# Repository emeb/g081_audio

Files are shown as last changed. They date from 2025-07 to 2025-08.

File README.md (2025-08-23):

# g081_audio

A Eurorack reverb module based on the STM32G081

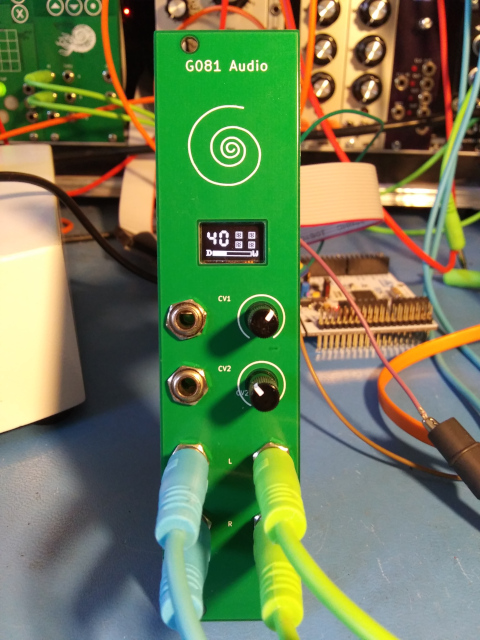
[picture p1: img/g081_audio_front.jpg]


## What it is

The G081 Audio module is an extremely simplified audio effects processor for Eurorack that's designed specifically to run the original MIDIVerb algorithms. Its audio conversion resolution is comparable to the original MIDIVerb and its processing power and memory capacity are just enough to handle the requirements of the algorithms. Essentially it is a proof-of-concept in minimalism.

## Background

In 2021 I was involved in a project to reverse-engineer the MIDIVerb which I've documented over here: [MIDIVerb_RE](https://github.com/emeb/MIDIVerb_RE). Once that effort was wrapped up I had some curiosity about how well those algorithms could be implemented on modern low-cost microprocessors so I did some tests that showed the initial emulation approach was too costly to run well on low-spec processors because there was considerable overhead in the the interpretation approach that was used. The alternative was to "compile" the algorithms into equivalent C code which could then be further optimized into fast machine code by high quality C compilers available today. This is the method used in the G081 Audio module.

## Hardware Features

The hardware of the module includes the following features:

- STM32G081KB Arm Cortex M0+ microcontroller
  - 64MHz
  - 128kB Flash
  - 36kB SRAM
  - 12-bit ADC with multipexed inputs
  - 2x 12-bit DACs
  - I2S, I2C and SPI ports
- PT8211 I2S stereo DAC
  - choice of on-chip DAC or I2S DAC for Euro-level audio outputs 
- Optional SPI flash chip (up to 32MB capacity)
- 12MHz crystal oscillator
- 64x32 I2C OLED display
- 2 CV inputs (+/-5V range with offset pots)
- Stereo audio inputs (12-bit resolution, +/-7V range)
- Stereo audio outputs (12- or 16-bit resolution, +/-7V range)
- 3.3V logic-level full-duplex serial port for diagnostics
- 6HP wide
- Standard 16-pin Euro power jack w/ shroud and reverse protection.

The main board has components on both sides - pots, jacks and OLED display on the front and all the remaining parts, including the Eurorack power jack on the back. The board has two "solder blob" type jumpers which allow selection of the output source - either the DACs internal to the STM32G081 or the PT8211 I2S DAC - the present firmware assumes the PT8211 is used. A footprint for an optional SPI flash chip is available although the present firmware does not require it.

## Firmware Features

The primary MIDIVerb software provides these features:

- 63 Original MIDIVerb algorithms selected by CV1
  - Smooth muting during program changes.
  - MIDIVerb algorithm number displayed on OLED.
  - Characteristics (duration, type) temporarily shown on display during changes.
- Wet/Dry mixing via CV2
  - Mix setting displayed on OLED.
- Input / Ouput level indicators
  - Low / normal / Clip level displayed as grayscale
- Compile-time option for OLED blanking.

## Design Collateral

This repository contains both Hardware and Firmware design info. Please refer to the README.md files withing the respective directories for further details.

[Hardware](./Hardware/README.md)

[Firmware](./Firmware/README.md)

## Build Notes

Since this project was first released there has been at least one alternate layout built by others in the community which unfortunately suffered from severe noise caused by the OLED which leaked into the audio path. The original layout provided here does not suffer from that problem so it's worthwhile noting that if you do choose to respin this design it would be wise to observe good layout principles:
- Maintain as contiguous a ground plane as is possible
- Think about the paths that supply and return currents are forced to take through your layout and how to keep the digital and analog paths separate.

In particular, the OLED is prone to generating strong current spikes when it is refreshing any active pixels and the PT8211 I2S DAC has very poor power supply rejection so when those two devices are present in the same design you must use care to keep them from fighting. I've provided a compile-time option to blank the OLED after a few seconds which can work around this issue but with good layout this should not be necessary.

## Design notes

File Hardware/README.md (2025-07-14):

# G081 Audio Hardware

This directory contains the KiCAD design files for the G081 Audio module, including both the passive front panel and the electrical rear panel.

A PDF schematic is available here: [G081 Audio Schematic](./g081_audio_schematic.pdf)

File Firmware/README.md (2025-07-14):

# G081 Audio - Firmware

This directory contains the firmware source code for the G081 Audio module. It's based on the STM32 HAL library, coupled with custom drivers for the external devices included in the G081 Audio module, such as the I2C OLED display and PT8211 stereo DAC. Note that while the hardware design includes a SPI flash it is not used in this firmware and would require additional code.

There are two build directories:

* audio - a skeleton for building applications that can process stereo audio.

* mv_comp - the Midiverb code using precompiled / optimized integer operations derived from the ROMs. The compiled code for baseline MIDIVerb algorithms is in the mv_progs.c file and was auto-generated with the compiler tools found in the [MIDIVerb_RE](https://github.com/emeb/MIDIVerb_RE) repository elsewhere in this collection.

## Prerequisites

You will need make and an Arm embedded cross compiler. I use the ones available here: [Arm GNU Toolchain Downloads – Arm Developer](https://developer.arm.com/downloads/-/arm-gnu-toolchain-downloads)

## Building

Once you've got your toolchain set up just

```
cd mv_comp
make
```

You may need to modify the Makefile to refer to the location of your toolchain.

## Programming

I use OpenOCD and an STM32 Nucleo board for programming. Note that there may be some special shenannigans required with the STM32G0 family on initial programming:

> `openocd -d0 -f stm32g0.cfg -c init -c "reset halt"  -c "mww 0x40022000 0x00040600"  -c "reset init" -c "reset run"  -c shutdown`
> 
> note the double reset
> 
> coz you need to reset AFTER you clear the EMPTY bit in FLASH->ACR
> 
> For reference - see the "empty check" paragraph in section 2.5 of the RM.

*Thanks to Vladimir Pantelic for that tip*

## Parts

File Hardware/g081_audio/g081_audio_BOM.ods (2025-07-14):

Reference | Value | Datasheet | Footprint | Qty
C1,C5,C7,C30 | 10uf | ~ | Capacitors_SMD:C_0805 | 4
C2,C3,C4,C6,C8,C9,C10,C15,C16,C17,C18,C24,C25 | 0.1uf |  | Capacitors_SMD:C_0603 | 13
C11,C12,C13,C14 | 330pf | ~ | Capacitors_SMD:C_0603 | 4
C19,C20,C23,C28 | 1uf | ~ | Capacitors_SMD:C_0603 | 4
C21,C22 | 3.3nf | ~ | Capacitors_SMD:C_0603 | 2
C26,C27 | 160pf | ~ | Capacitors_SMD:C_0603 | 2
C29 | 0.01uf | ~ | Capacitors_SMD:C_0603 | 1
D1,D2 | D | ~ | Diodes_SMD:D_SMA | 2
FB1,FB2,FB3 | 220 | ~ | Resistors_SMD:R_0805 | 3
J1 | Serial | ~ | Pin_Headers:Pin_Header_Straight_1x03_Pitch2.54mm | 1
J2 | SWD | ~ | Pin_Headers:Pin_Header_Straight_1x05_Pitch2.54mm | 1
J4,J5,J6,J7,J9,J10 | AudioJack2_SwitchT | ~ | footprints:Jack_3.5mm_QingPu_WQP-PJ398SM_Vertical_CircularHoles | 6
J8 | Conn_02x08_Odd_Even | ~ | footprints:5103308-3 | 1
R1 | 1.5k | ~ | Resistors_SMD:R_0603 | 1
R2,R4,R6,R7,R8,R9,R22,R23 | 100k | ~ | Resistors_SMD:R_0603 | 8
R3,R5 | 49.9k | ~ | Resistors_SMD:R_0603 | 2
R10,R11 | 33k | ~ | Resistors_SMD:R_0603 | 2
R12,R13 | 24.9k | ~ | Resistors_SMD:R_0603 | 2
R14,R15,R16,R17 | 180 | ~ | Resistors_SMD:R_0603 | 4
R18,R19,R20,R21 | 12.5k | ~ | Resistors_SMD:R_0603 | 4
R24,R25 | 100 | ~ | Resistors_SMD:R_0603 | 2
R26,R27 | 50k | ~ | Resistors_SMD:R_0603 | 2
R?,RV1,RV2 | 10k | ~ | -- mixed values -- | 3
U1 | 12MHz |  | Oscillators:Oscillator_SMD_SeikoEpson_SG210-4pin_2.5x2.0mm | 1
U2 | MCP1802x-xx02xOT | http://ww1.microchip.com/downloads/en/DeviceDoc/22053C.pdf | Package_TO_SOT_SMD:SOT-23-5 | 1
U3 | STM32G081KB |  | Housings_QFP:LQFP-32_7x7mm_Pitch0.8mm | 1
U4 | W25Q32JVSS | http://www.winbond.com/resource-files/w25q32jv%20revg%2003272018%20plus.pdf | footprints:SOIC-8_208mil_Pitch1.27mm | 1
U5 | PT8211 |  | Housings_SOIC:SOIC-8_3.9x4.9mm_Pitch1.27mm | 1
U6 | LM4040DBZ-5 | http://www.ti.com/lit/ds/symlink/lm4040-n.pdf | Package_TO_SOT_SMD:SOT-23 | 1
U7 | MCP6004 | http://www.ti.com/lit/ds/symlink/tl081.pdf | Housings_SSOP:TSSOP-14_4.4x5mm_Pitch0.65mm | 1
U8 | LM1117-5.0 | http://www.ti.com/lit/ds/symlink/lm1117.pdf | TO_SOT_Packages_SMD:SOT-223-3_TabPin2 | 1
U9 | TL072PW | http://www.ti.com/lit/ds/symlink/tl081.pdf | Housings_SSOP:TSSOP-8_4.4x3mm_Pitch0.65mm | 1
U10 | LP2985-3.3 | http://www.ti.com/lit/ds/symlink/lp2985.pdf | Package_TO_SOT_SMD:SOT-23-5 | 1
U11 | OLED_I2C |  | footprints:OLED_I2C_64x32_0.95 | 1

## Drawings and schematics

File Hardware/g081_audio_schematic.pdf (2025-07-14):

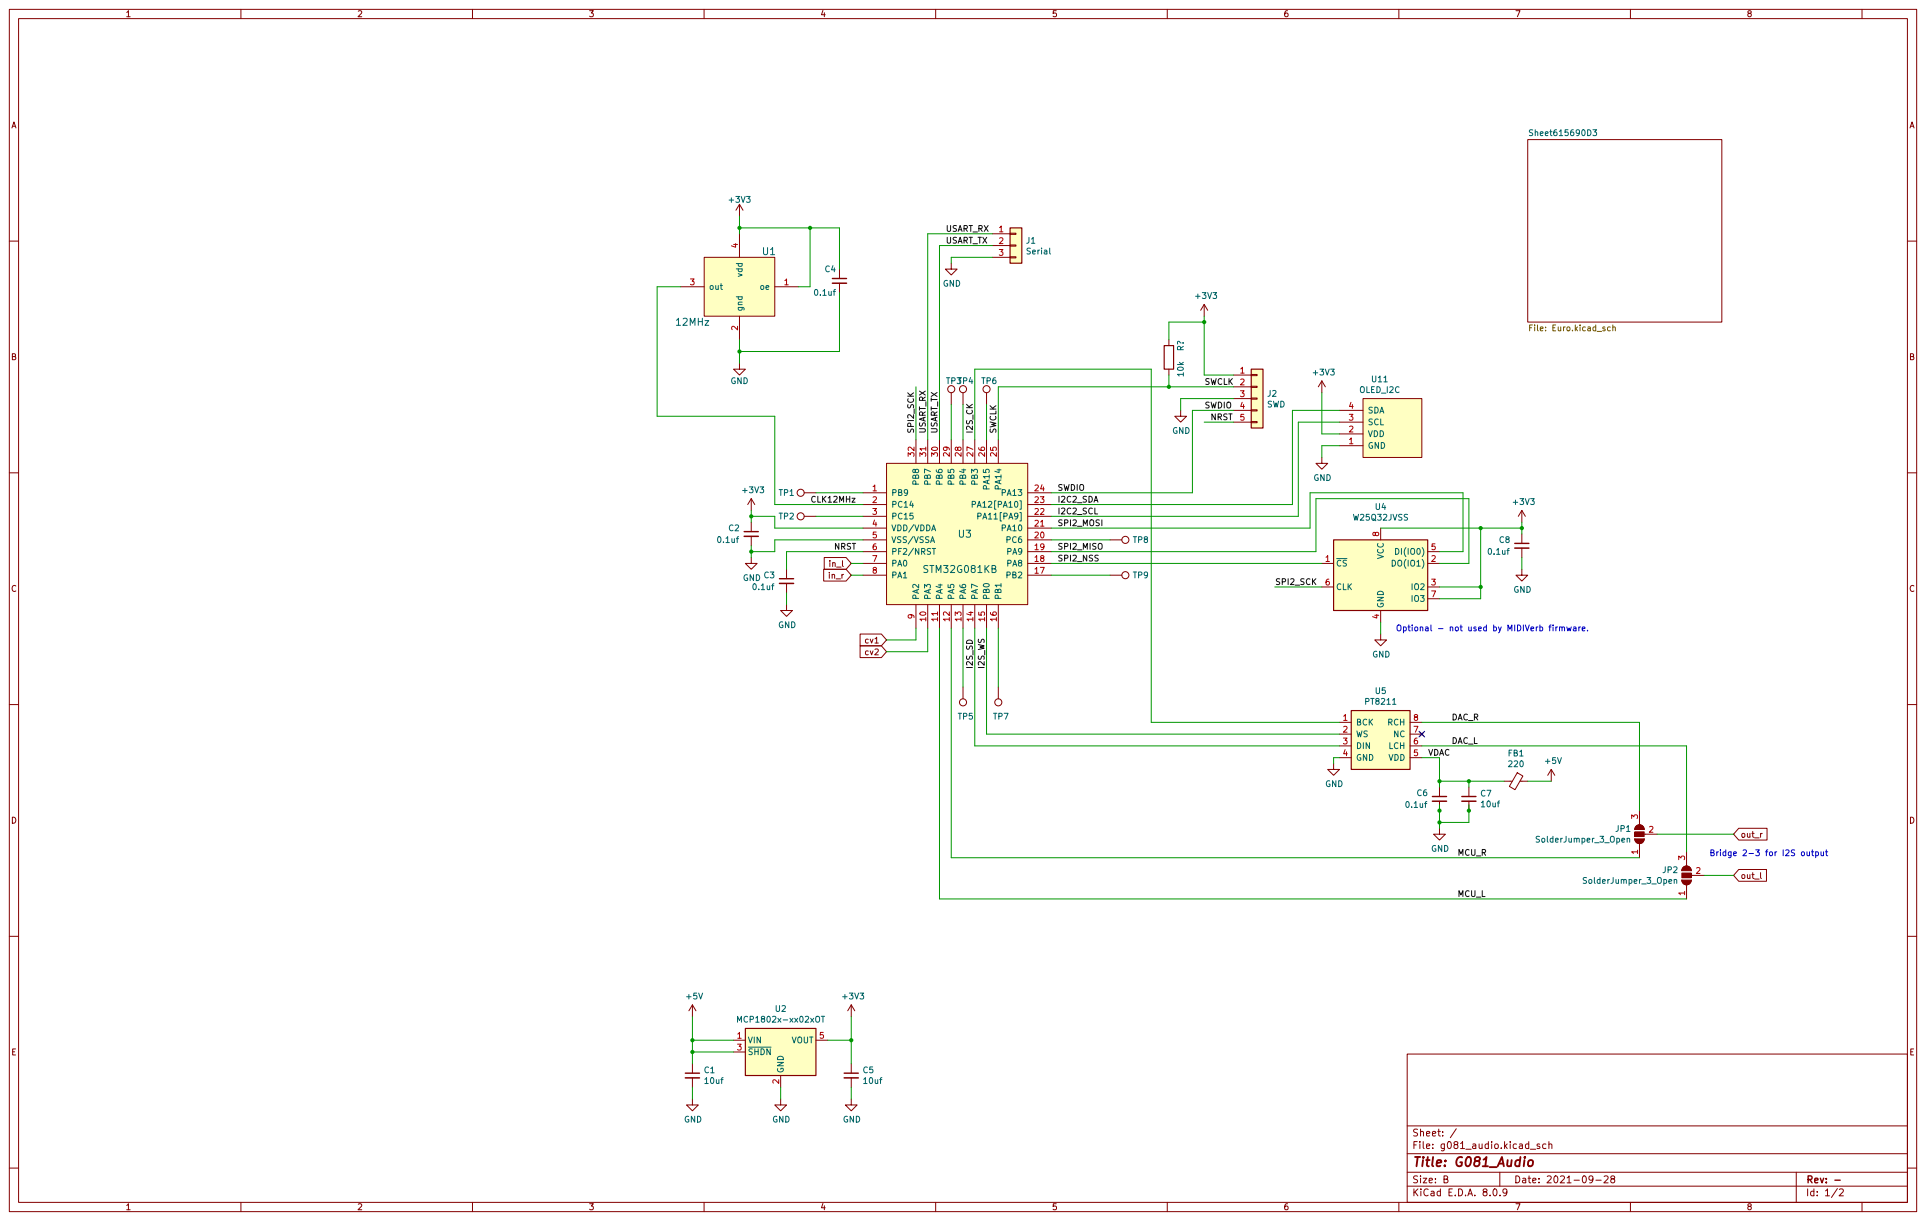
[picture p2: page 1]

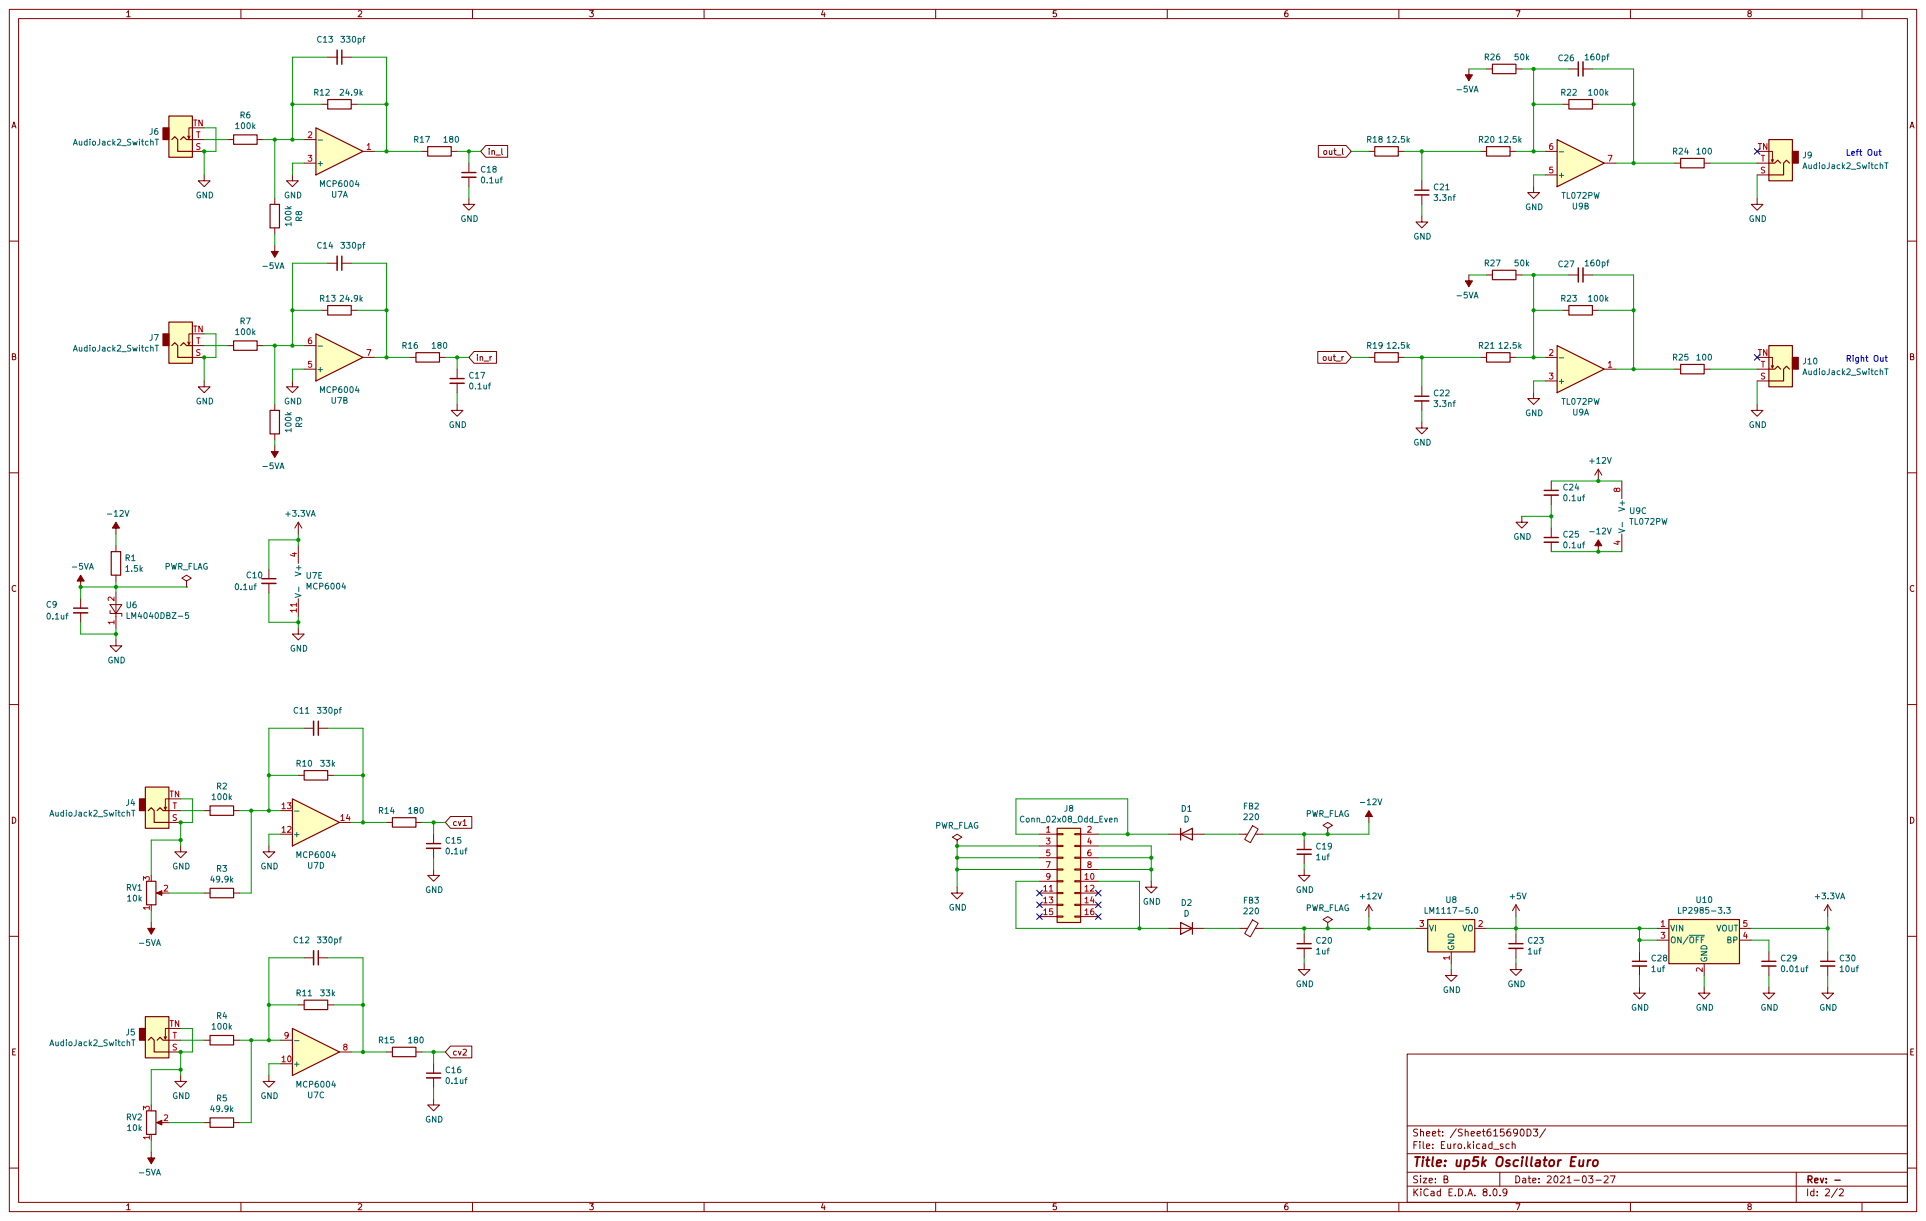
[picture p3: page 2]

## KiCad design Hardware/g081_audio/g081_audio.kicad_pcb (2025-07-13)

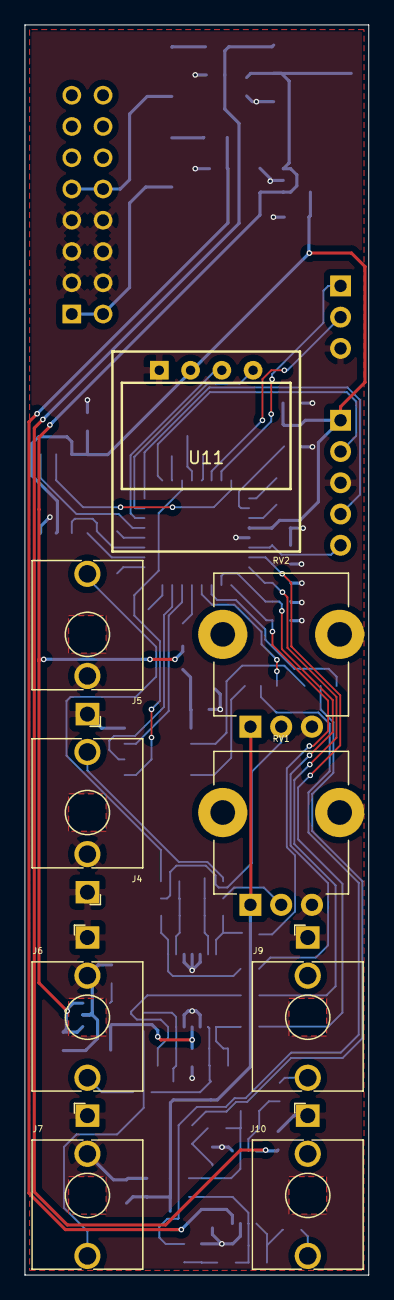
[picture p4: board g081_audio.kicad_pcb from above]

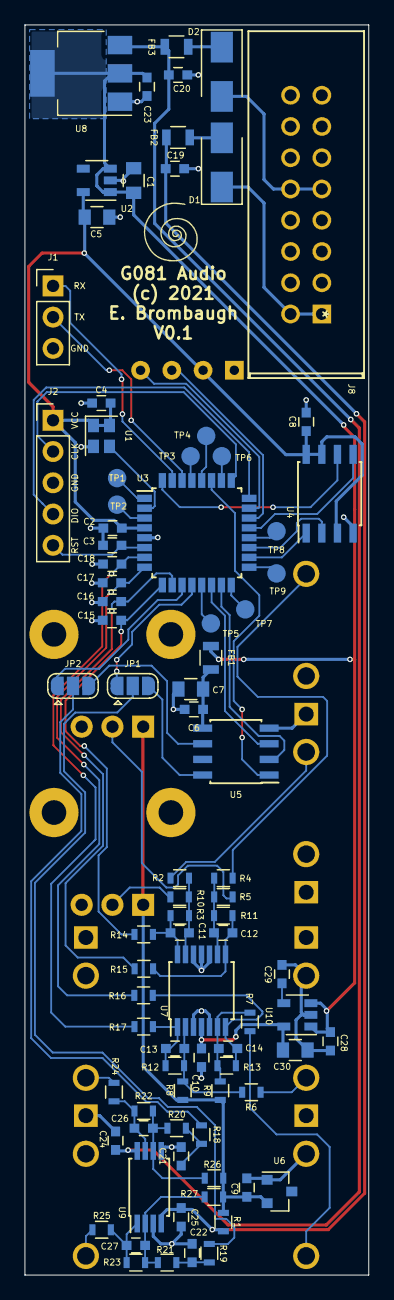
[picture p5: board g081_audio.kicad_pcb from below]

Board: 2 copper layers, 27.9 x 101.6 mm, 96 parts (87 on the bottom side), 69 nets.

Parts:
C1, C5, C7, C30: 10uf; C_0805
C2, C3, C4, C6, C8, C9, C10, C24, C25: 0.1uf; C_0603
C11, C12, C13, C14: 330pf; C_0603
C15, C16, C17, C18, C29: 0.01uf; C_0603
C19, C20, C23, C28: 1uf; C_0603
C21, C22: 4.7nf; C_0603
C26, C27: 75pf; C_0603
D1, D2: D; D_SMA
FB1, FB2, FB3: 220; R_0805
J1: Serial; Pin_Header_Straight_1x03_Pitch2.54mm
J2: SWD; Pin_Header_Straight_1x05_Pitch2.54mm
J4, J5, J6, J7, J9, J10: AudioJack2_SwitchT; Jack_3.5mm_QingPu_WQP-PJ398SM_Vertical_CircularHoles
J8: Conn_02x08_Odd_Even; 5103308-3
JP1, JP2: SolderJumper_3_Open; SolderJumper-3_P1.3mm_Open_RoundedPad1.0x1.5mm
R1: 1.5k; R_0603
R2, R4, R6, R7, R8, R9: 100k; R_0603
R3, R5: 49.9k; R_0603
R10, R11, R12, R13: 33k; R_0603
R14, R15, R16, R17, R24, R25: 100; R_0603
R18, R19: 1k; R_0603
R20, R21: 16k; R_0603
R22, R23, R26, R27: 71.5k; R_0603
RV1, RV2: 10k; Potentiometer_TT_P0915N
Ref**: Val**; avatar_small
TP1, TP2, TP3, TP4, TP5, TP6, TP7, TP8, TP9: TestPoint; Measurement_Point_Round-SMD-Pad_Small
U1: 12MHz; Oscillator_SMD_SeikoEpson_SG210-4pin_2.5x2.0mm
U2: MCP1802x-xx02xOT; SOT-23-5
U3: STM32G081KB; LQFP-32_7x7mm_Pitch0.8mm
U4: W25Q32JVSS; SOIC-8_208mil_Pitch1.27mm
U5: PT8211; SOIC-8_3.9x4.9mm_Pitch1.27mm
U6: LM4040DBZ-5; SOT-23
U7: MCP6004; TSSOP-14_4.4x5mm_Pitch0.65mm
U8: LM1117-5.0; SOT-223-3_TabPin2
U9: TL072PW; TSSOP-8_4.4x3mm_Pitch0.65mm
U10: LP2985-3.3; SOT-23-5
U11: OLED_I2C; OLED_I2C_64x32_0.95

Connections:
+3.3VA: C10.1, C30.1, U7.4, U10.5
+3V3: C2.1, C4.1, C5.1, C8.1, J2.1, U1.1, U1.4, U2.5, U3.4, U4.3, U4.7, U4.8, U11.2
+5V: C1.1, C23.1, C28.1, FB1.1, U2.1, U2.3, U8.2, U10.1, U10.3
+12V: C20.1, C24.1, FB3.1, U8.3, U9.8
-5VA: C9.1, R1.1, R8.1, R9.1, R26.2, R27.2, RV1.1, RV2.1, U6.2
-12V: C19.1, C25.2, FB2.1, R1.2, U9.4
/CLK12MHz: U1.3, U3.2
/DAC_L: JP2.3, U5.6
/DAC_R: JP1.3, U5.8
/I2C2_SCL: U3.22, U11.3
/I2C2_SDA: U3.23, U11.4
/I2S_CK: U3.27, U5.1
/I2S_SD: U3.14, U5.3
/I2S_WS: U3.15, U5.2
/MCU_L: JP2.1, U3.11
/MCU_R: JP1.1, U3.12
/NRST: C3.1, J2.5, U3.6
/SPI2_MISO: U3.19, U4.2
/SPI2_MOSI: U3.21, U4.5
/SPI2_NSS: U3.18, U4.1
/SPI2_SCK: U3.32, U4.6
/SWCLK: J2.2, U3.25
/SWDIO: J2.4, U3.24
/USART_RX: J1.1, U3.31
/USART_TX: J1.2, U3.30
/VDAC: C6.1, C7.1, FB1.2, U5.5
GND: C1.2, C2.2, C3.2, C4.2, C5.2, C6.2, C7.2, C8.2, C9.2, C10.2, C15.2, C16.2, C17.2, C18.2, C19.2, C20.2, C21.2, C22.2, C23.2, C24.2, C25.1, C28.2, C29.2, C30.2, J1.3, J2.3, J4.S, J4.TN, J5.S, J5.TN, J6.S, J6.TN, J7.S, J7.TN, J8.3, J8.4, J8.5, J8.6, J8.7, J8.8, J9.S, J10.S, RV1.3, RV2.3, U1.2, U2.2, U3.5, U4.4, U5.4, U6.1, U7.3, U7.5, U7.10, U7.11, U7.12, U8.1, U9.3, U9.5, U10.2, U11.1
unnamed: C11.1, R10.1, R14.2, U7.14
unnamed: C11.2, R2.1, R3.1, R10.2, U7.13
unnamed: C12.1, R11.1, R15.2, U7.8
unnamed: C12.2, R4.1, R5.1, R11.2, U7.9
unnamed: C13.1, R12.1, R17.2, U7.1
unnamed: C13.2, R6.1, R8.2, R12.2, U7.2
unnamed: C14.1, R13.1, R16.2, U7.7
unnamed: C14.2, R7.1, R9.2, R13.2, U7.6
unnamed: C21.1, R18.1, R20.2
unnamed: C22.1, R19.1, R21.2
unnamed: C26.1, R20.1, R22.2, R26.1, U9.6
unnamed: C26.2, R22.1, R24.2, U9.7
unnamed: C27.1, R21.1, R23.2, R27.1, U9.2
unnamed: C27.2, R23.1, R25.2, U9.1
unnamed: C29.1, U10.4
unnamed: D1.1, J8.1, J8.2
unnamed: D1.2, FB2.2
unnamed: D2.1, FB3.2
unnamed: D2.2, J8.9, J8.10
unnamed: J4.T, R2.2
unnamed: J5.T, R4.2
unnamed: J6.T, R6.2
unnamed: J7.T, R7.2
unnamed: J9.T, R24.1
unnamed: J10.T, R25.1
unnamed: R3.2, RV1.2
unnamed: R5.2, RV2.2
unnamed: TP1.1, U3.1
unnamed: TP2.1, U3.3
unnamed: TP3.1, U3.29
unnamed: TP4.1, U3.28
unnamed: TP5.1, U3.13
unnamed: TP6.1, U3.26
unnamed: TP7.1, U3.16
unnamed: TP8.1, U3.20
unnamed: TP9.1, U3.17
cv1: C15.1, R14.1, U3.9
cv2: C16.1, R15.1, U3.10
in_l: C18.1, R17.1, U3.7
in_r: C17.1, R16.1, U3.8
out_l: JP2.2, R18.2
out_r: JP1.2, R19.2

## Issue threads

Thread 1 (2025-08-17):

Problems to programm the STM

stilltryin, 2025-08-17:
Hi, I tried to programm the STM with ST-LINKv2, with a UART dongle and another one I had, but no luck. Any idea what I am doing wrong...got the firmware compiled to a hex file but can't even see the STM in Cube Programmer...

stilltryin, 2025-08-19:
Maybe an issue from the display? Put a sleep routine in like 2sec after active go to sleep?

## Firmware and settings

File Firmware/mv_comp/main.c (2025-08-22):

/*
 * main.c - G081 audio - Midiverb Compiled
 * E. Brombaugh 09-28-2021
 */

#include "stm32g0xx_hal.h"
#include "usart.h"
#include "printf.h"
#include "audio.h"
#include "adc.h"
#include "shared_i2c.h"
#include "oled.h"
#include "timersleep.h"
#include "i2s.h"
#include "widget.h"
#include "mv_names.h"

/*
 * Optional OLED blanking - uncomment the following line if you want to
 * enable the OLED screensaver to darken the display after several seconds
 * The timeout is user selectable in milliseconds
 */
//#define OLED_BLANK_ENABLE
#define OLED_BLANK_TIMEOUT 3000

/**
  * @brief  This function is executed in case of error occurrence.
  * @retval None
  */
void Error_Handler(void)
{
}

/**
  * @brief System Clock Configuration
  * @retval None
  */
void SystemClock_Config(void)
{
  RCC_OscInitTypeDef RCC_OscInitStruct = {0};
  RCC_ClkInitTypeDef RCC_ClkInitStruct = {0};
  RCC_PeriphCLKInitTypeDef PeriphClkInit = {0};

  /** Configure the main internal regulator output voltage
  */
  HAL_PWREx_ControlVoltageScaling(PWR_REGULATOR_VOLTAGE_SCALE1);
  /** Initializes the RCC Oscillators according to the specified parameters
  * in the RCC_OscInitTypeDef structure.
  */
  RCC_OscInitStruct.OscillatorType = RCC_OSCILLATORTYPE_HSI;
  RCC_OscInitStruct.HSIState = RCC_HSI_ON;
  RCC_OscInitStruct.HSIDiv = RCC_HSI_DIV1;
  RCC_OscInitStruct.HSICalibrationValue = RCC_HSICALIBRATION_DEFAULT;
  RCC_OscInitStruct.PLL.PLLState = RCC_PLL_ON;
  RCC_OscInitStruct.PLL.PLLSource = RCC_PLLSOURCE_HSI;
  RCC_OscInitStruct.PLL.PLLM = RCC_PLLM_DIV2;
  RCC_OscInitStruct.PLL.PLLN = 16;
  RCC_OscInitStruct.PLL.PLLP = RCC_PLLP_DIV2;
  RCC_OscInitStruct.PLL.PLLQ = RCC_PLLQ_DIV2;
  RCC_OscInitStruct.PLL.PLLR = RCC_PLLR_DIV2;
  if (HAL_RCC_OscConfig(&RCC_OscInitStruct) != HAL_OK)
  {
    Error_Handler();
  }
  /** Initializes the CPU, AHB and APB buses clocks
  */
  RCC_ClkInitStruct.ClockType = RCC_CLOCKTYPE_HCLK|RCC_CLOCKTYPE_SYSCLK
                              |RCC_CLOCKTYPE_PCLK1;
  RCC_ClkInitStruct.SYSCLKSource = RCC_SYSCLKSOURCE_PLLCLK;
  RCC_ClkInitStruct.AHBCLKDivider = RCC_SYSCLK_DIV1;
  RCC_ClkInitStruct.APB1CLKDivider = RCC_HCLK_DIV1;

  if (HAL_RCC_ClockConfig(&RCC_ClkInitStruct, FLASH_LATENCY_2) != HAL_OK)
  {
    Error_Handler();
  }
  /** Initializes the peripherals clocks
  */
  PeriphClkInit.PeriphClockSelection = RCC_PERIPHCLK_USART2|RCC_PERIPHCLK_ADC
                              |RCC_PERIPHCLK_TIM1;
  PeriphClkInit.Usart2ClockSelection = RCC_USART2CLKSOURCE_PCLK1;
  PeriphClkInit.AdcClockSelection = RCC_ADCCLKSOURCE_SYSCLK;
  PeriphClkInit.Tim1ClockSelection = RCC_TIM1CLKSOURCE_PCLK1;
  if (HAL_RCCEx_PeriphCLKConfig(&PeriphClkInit) != HAL_OK)
  {
    Error_Handler();
  }
}

/*
 * quantize 12-bit CV into arbitrary ranges with hysteresis
 */
uint8_t ratio_hyst_arb(uint16_t *old, uint16_t in, uint8_t range)
{
	uint8_t result = 0;
	int16_t diff, guard, scale, rnd;
    
    /* compute scaling to achieve range */
    scale = 4096/range;
    rnd = scale/2;
    
    /* set guard band */
    guard = 2*scale/3;
    guard = (guard == 0) ? 1 : guard;
    
	/* Special case - don't guardband at endpoints */
	if((in == 0) || (in == 0xFFF))
	{
		diff = (in+rnd) / scale;
		if(diff == *old)
			return 0;
		else
		{
			*old = diff;
			return 1;
		}
	}
	
	/* find abs val of diff */
	diff = (int16_t)(*old * scale) - (int16_t)in;
	if(diff<0)
		diff = -diff;
	
	/* exceeds guardband ? */
	if(diff > guard)
	{
		/* yes so update prev */
		*old  = (in+rnd) / scale;
		result = 1;
	}
	
	return result;
}

/*
 * main routine
 */
int main(void)
{
	uint16_t prog = 255, dcnt = 0;
	uint32_t slowgoal;
#ifdef OLED_BLANK_ENABLE
	uint32_t blankgoal;
	uint8_t blanked;
#endif
	
	/* Reset of all peripherals, Initializes the Flash interface and the Systick. */
	HAL_Init();

	__HAL_RCC_SYSCFG_CLK_ENABLE();
	__HAL_RCC_PWR_CLK_ENABLE();

	/* Configure the system clock */
	SystemClock_Config();

	/* init the UART for diagnostics */
	setup_usart();
	init_printf(0,usart_putc);
	printf("\n\n\rG081 Audio MV Compiled\n\r");
	printf("\n");
	printf("SYSCLK = %d\n\r", HAL_RCC_GetSysClockFreq());
	printf("\n");
	
	/* microsecond timer */
	timersleep_init();
	printf("timersleep enabled\n\r");
	
	/* I2C */
	shared_i2c_init();
	printf("I2C initialized\n\r");

	/* OLED */
	printf("OLED initialized - result = %d\n\r", oled_init());
	
	/* Audio */
	Audio_Init();
	printf("Audio initialized\n\r");	

	/* DAC */
	i2s_init();
	printf("I2S initialized\n\r");
	
	/* ADC */
	ADCInit();
	i2s_start();
	printf("ADC initialized, I2S started\n\r");
	
    /* Infinite loop */
	slowgoal = timersleep_goal_ms(100);
#ifdef OLED_BLANK_ENABLE
	blankgoal= timersleep_goal_ms(OLED_BLANK_TIMEOUT);
	blanked = 0;
#endif
    while(1)
    {
		/* quantize prog cv to number of progs & update */
		if(ratio_hyst_arb(&prog, cvbuf[0], 62))
		{
			printf("\n prog = %d\n\r", prog);
			Audio_SetProg(prog);
			oled_draw_7seg_2dRJ(0, 1, 1, prog+1, 1);
			oled_drawstr(0, 0, 25, (char *)mv_prog_names[prog], 0);
			dcnt = 20;
			oled_refresh(0);
#ifdef OLED_BLANK_ENABLE
			blankgoal= timersleep_goal_ms(OLED_BLANK_TIMEOUT);
			blanked = 0;
#endif
		}
		
		/* stuff that happens at a slower rate */
		if(!timersleep_check(slowgoal))
		{
			slowgoal = timersleep_goal_ms(100);
			
			//printf("CV 1: 0x%03X, ", cvbuf[0]);
			//printf("CV 2: 0x%03X, ", cvbuf[1]);
			//printf("L DC: %5d, ", dcb[0]>>11);
			//printf("R DC: %5d, ", dcb[1]>>11);
			printf("LI lvl: %5d, ", sl[0]);
			printf("RI lvl: %5d, ", sl[1]);
			printf("LO lvl: %5d, ", sl[2]);
			printf("RO lvl: %5d, ", sl[3]);
			printf("\r");
			
			/* update signal level indicators */
			level_indicator(0, 36, 2, sl[0]);
			sl[0] = 0;
			level_indicator(0, 36, 14, sl[1]);
			sl[1] = 0;
			level_indicator(0, 52, 2, sl[2]);
			sl[2] = 0;
			level_indicator(0, 52, 14, sl[3]);
			sl[3] = 0;			
			
			/* name timeout */
			if(dcnt<2)
			{
				if(dcnt == 1)
				{
					dcnt = 0;
					oled_drawrect(0, 0, 25, 64, 8, 0);
				}
				
				/* update w/d mix bar */
				oled_drawchar(0, 0, 25, 'D', 1);
				oled_drawchar(0, 57, 25, 'W', 1);
				bargraphH(0, 8, 26, 48, 6, (100*cvbuf[1])>>12);
#ifdef OLED_BLANK_ENABLE
				if(!blanked)
					oled_refresh(0);
#else
				oled_refresh(0);
#endif
			}
			else
			{
				dcnt--;
			}
		}
		
#ifdef OLED_BLANK_ENABLE
		/* check for blanking */
		if(!blanked && !timersleep_check(blankgoal))
		{
			/* clear the screen */
			blanked = 1;
			oled_clear(0,0);
			oled_refresh(0);
		}
#endif
    }
}

/*
 * needed by HAL
 */
void SysTick_Handler(void)
{
  HAL_IncTick();
}

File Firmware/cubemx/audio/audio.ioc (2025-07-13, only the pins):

Mcu.UserName=STM32G081KBTx
PA0.Signal=ADC1_IN0
PA1.Signal=ADC1_IN1
PA10.Signal=SPI2_MOSI
PA13.Signal=SYS_SWDIO
PA14-BOOT0.Signal=SYS_SWCLK
PA2.Signal=ADC1_IN2
PA3.Signal=ADC1_IN3
PA4.Signal=COMP_DAC11_group
PA5.Signal=COMP_DAC12_group
PA7.Signal=I2S1_SD
PA8.Signal=SPI2_NSS
PA9.Signal=SPI2_MISO
PB0.Signal=I2S1_WS
PB1.Signal=TIM1_CH3N
PB3.Signal=I2S1_CK
PB6.Signal=USART1_TX
PB7.Signal=USART1_RX
PB8.Signal=SPI2_SCK

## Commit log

2025-07-13 Initial checkin
    [Euro.kicad_sch, audio_panel.kicad_pcb, audio_panel.kicad_sch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]
2025-07-14 Added schematic and more documentation.
    [Euro.kicad_sch, g081_audio.kicad_sch]
2025-07-14 Schematic updates - printing prefs, text notes, input gain, BOM.
    [Euro.kicad_sch, g081_audio.kicad_sch, g081_audio_BOM.ods]

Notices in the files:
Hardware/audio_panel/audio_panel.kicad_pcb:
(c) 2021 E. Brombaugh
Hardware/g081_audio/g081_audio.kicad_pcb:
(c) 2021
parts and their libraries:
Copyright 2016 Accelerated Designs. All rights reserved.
